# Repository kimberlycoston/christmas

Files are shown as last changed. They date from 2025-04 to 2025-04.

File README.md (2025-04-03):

# christmas
cd existing_repo
git remote add origin https://gitlab.oit.duke.edu/coston_individual2_aipi590/coston_individual2_aipi590.git
git branch -M main
git push -uf origin main
# Christmas in a Box

A festive, plug-and-play projection mapping system that lights up your home—without the hassle, cost, or danger of traditional holiday lights.

## 📌 Table of Contents
Introduction  
Features  
Hardware & Software Requirements  
Installation & Setup  
How It Works  
Challenges  
Next Steps  
Acknowledgments  
License  

## 📝 Introduction
This project is a holiday light projection mapping system built using a Raspberry Pi, camera, and mini projector housed inside a themed “gingerbread house” container. It captures the shape of a house and overlays light animations—bringing joy utilizing computer vision.

### 💡 Why This Matters?

Hanging outdoor holiday lights is time-consuming and risky

Hiring professionals is expensive

This system offers a safer, fun, and automated alternative using computer vision and projection mapping

This project runs locally on a Raspberry Pi for low-cost, real-time processing.

### 🔹 Features
✔️ Automatically detects house shape using Pi Camera
✔️ Projects holiday lights and animations without physical setup
✔️ Portable "Christmas in a Box" housing
✔️ Interactive servo-powered features (e.g., sliding door, LCD display, holiday audio jingle)
✔️ Runs entirely on a Raspberry Pi  

## 💻 Hardware & Software Requirements
### 🔧 Hardware:
Raspberry Pi 4  
Mini Projector  
Pi Camera  
Continuous Servo Motor (for gingerbread house door)  
Button (to capture photo)  
Button (to open/close door)  
LED Display  
Real-time Clock Module  
Containment device (custom-built gingerbread house enclosure)  
USB Cable, HDMI Cable, Power Supply (5V Battery Pack), Wires, Breadboard  



### 📦 Software:
Python 3.7+    
NumPy  
OpenCV  
VLC (for video projection demo)  
Roboflow  
Window Object Detection Dataset for computer vision model (Project ID: door-window-detection-pipvh-xcnsz)  
Roof & Trim Instance Segmentation Dataset for computer vision model (Project ID: dzinlyinstancesegmentation-welbr)  

## ⚙️ Installation & Setup
### Step 1: Clone the Repository
git clone https://gitlab.oit.duke.edu/coston_individual2_aipi590/coston_individual2_aipi590.git 
cd christmas 

### Step 2: Install Dependencies
pip install -r requirements.txt  

### Step 3: Hardware Assembly
Connect Pi Camera to Raspberry Pi via ribbon  
Connect Mini Projector to Raspberry Pi via HDMI cable  
Connect buttons, RTC module, passive buzzer, and LCD display using GPIO pins  
Create track for door to run on servo motor (.stl files for 3D printed rack & pinion; can choose between two sizes of pinions)  
Secure all components inside your chosen [e.g., gingerbread house] enclosure (.svg files for laser cut gingerbread house)  

### Step 4: Run the Program
Press the button to demo the system (will open/close door via servo)  
Press the second button and camera captures and maps the projection area  
Light animation video plays through the projector     

## 📊 How It Works
User sets up the “Christmas in a Box” facing their house  
Press button → servo opens door → projector lens revealed  
Pi Camera captures house image  
OpenCV detects edges or key shapes (windows, roofline)  
Light animation is aligned to contours and projected  
Servo and buzzer add interactive, festive effects :)  

### 📌 Flowchart of the System:
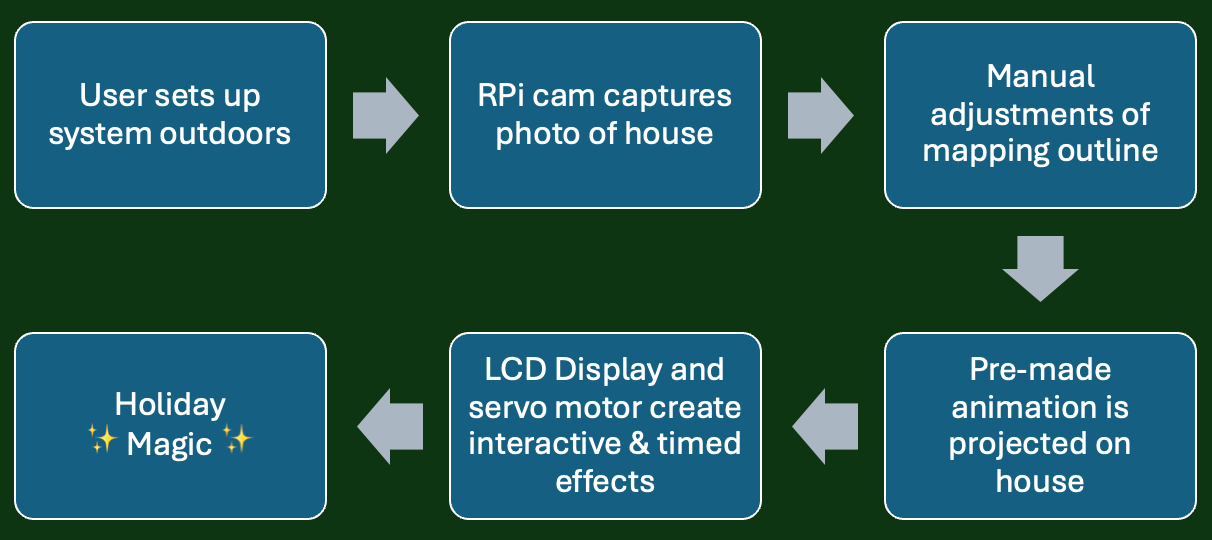
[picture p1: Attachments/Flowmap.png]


## 🚧 Challenges
🔴 IR Blaster Integration  
Initially planned for IR-controlled lights but ran into signal issues; feature was skipped in final build.

🔴 Containment Device Design  
Multiple iterations on how to house all components—limited space and aesthetics were hard to balance.

🔴 Servo Timing & Constraints  
Servo motor movement had to be extremely precise within the tight enclosure space.

🔴 Projection Alignment Issues  
Accurate projection mapping onto the house was challenging—OpenCV had trouble with lighting variation and inconsistent surfaces.

## 🚀 Next Steps
✔️ Improve projection alignment accuracy  
✔️ Add customizable light themes and interactive modes  
✔️ Find a work-around IR or wireless syncing with external light devices  
✔️ Upgrade detection system for better edge and feature detection  
✔️ Add mobile or voice control for convenience  

## 📜 License
This project is licensed under the MIT License – feel free to use and modify it.

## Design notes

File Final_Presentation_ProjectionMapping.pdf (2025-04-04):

# Holiday Light

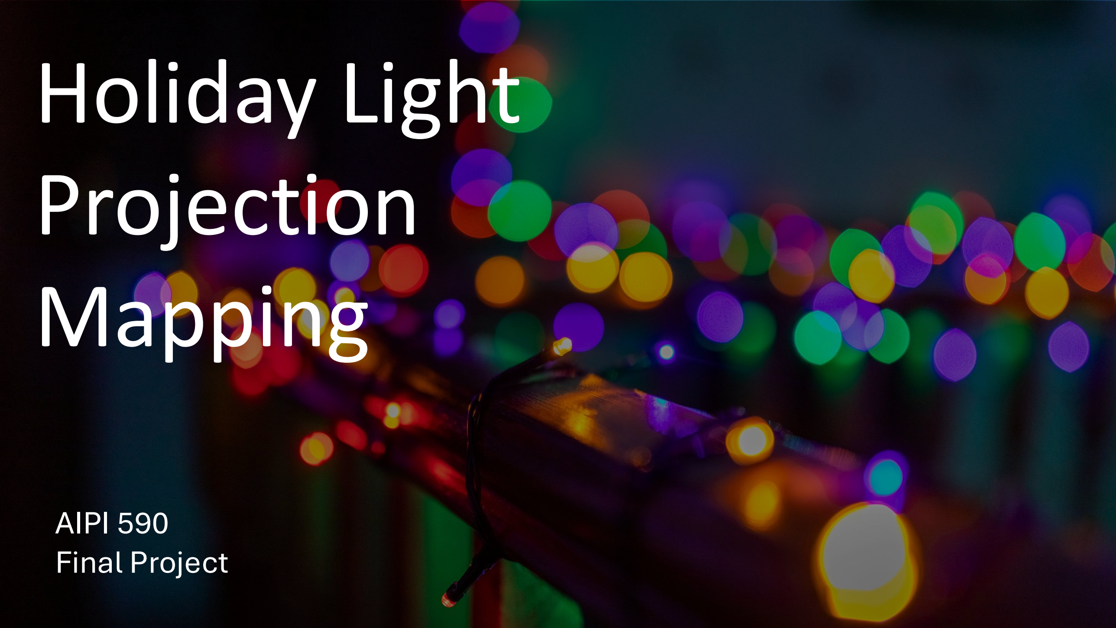
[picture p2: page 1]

# Projection Mapping

AIPI 590
Final Project

# Background: Time, Cost, & Safety

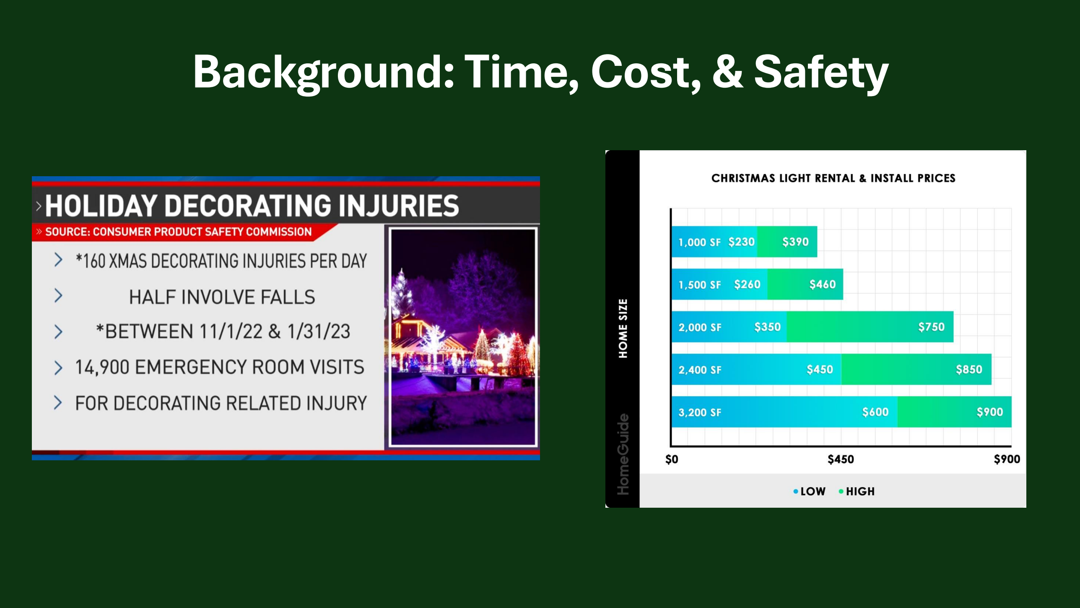
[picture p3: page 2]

# Sensors, Inputs, & Peripherals

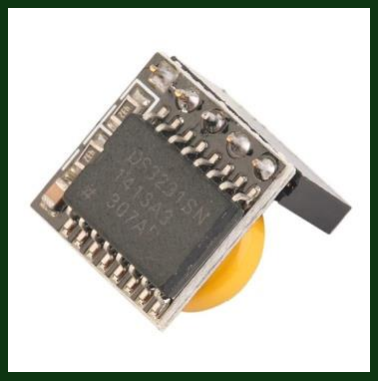
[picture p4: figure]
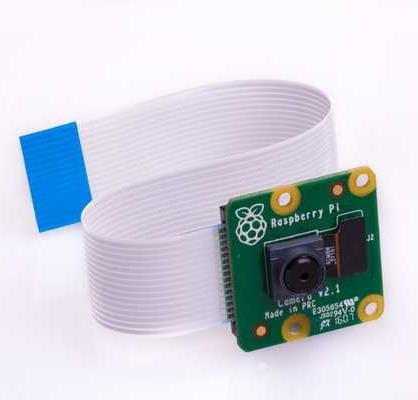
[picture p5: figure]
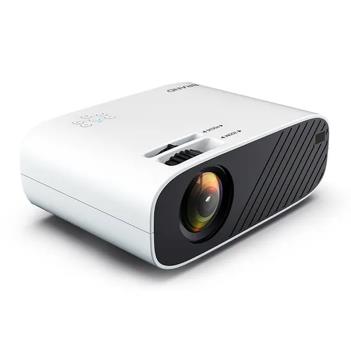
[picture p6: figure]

- RPi Camera Module 2
- Push Button x2

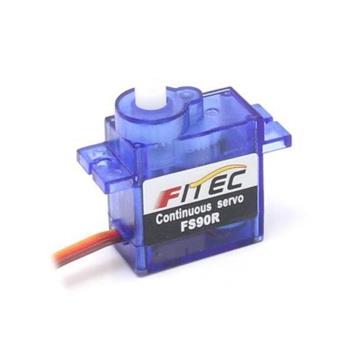
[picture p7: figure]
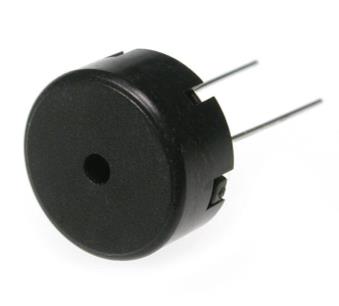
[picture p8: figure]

- DS3231 Real Time Clock Module
- LCD 16x2 Display
- Passive Buzzer
- FS90R Continuous Servo Motor
- Mini Projector

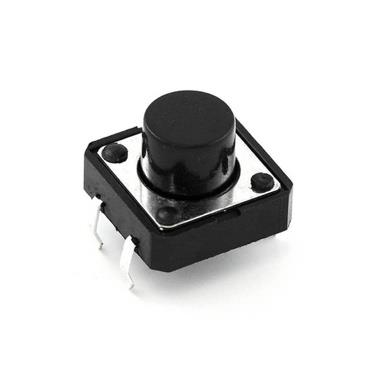
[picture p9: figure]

# Dataset + Model Prediction

Model
- Instance segmentation
- Ultralytics YOLOv8n
- Roboflow
- 298 images
- Epochs: 50
Class | Precision | Recall | mAP@0.5 | mAP@0.5:0.95
Roof | 0.678 | 0.812 | 0.828 | 0.704
Trim | 0.772 | 0.640 | 0.774 | 0.550
Window | 0.884 | 0.822 | 0.930 | 0.772

Postprocessing
- Extract external contours via OpenCV
- Apply class-specific filtering:
- Window: convert to bounding rectangle
- Trim: Keep as polyline, no mask fill
- Roof: smooth shape, remove jittery edges Model Performance

# Postprocessing Example

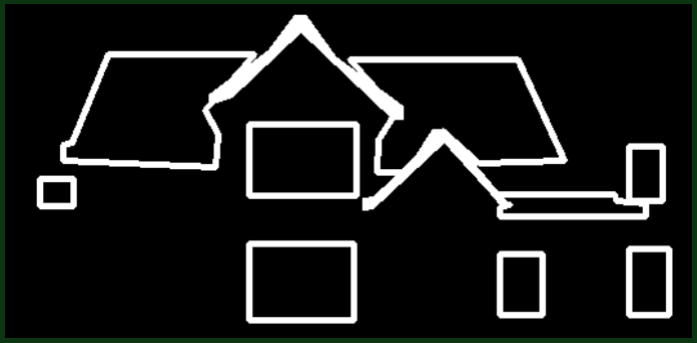
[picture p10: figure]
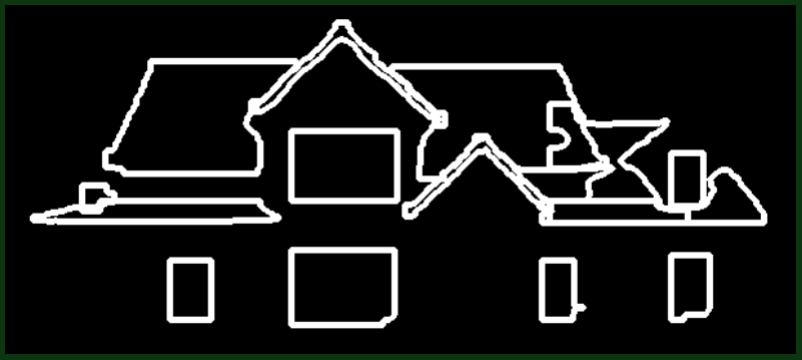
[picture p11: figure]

# Process

## Control Module

- Servo control
- LCD screen feedback
- Sound effects
- RTC time tracking
- Demo button

## Vision Module

- capture_utils
- yolo_utils
- ui_utils
- edit_utils

## Projection Module

- Overlay GIFs
- Sends to projector

# Challenges

## - IR blaster integration - Designing the container - Servo motor precision - Projection mapping accuracy

# How it Works

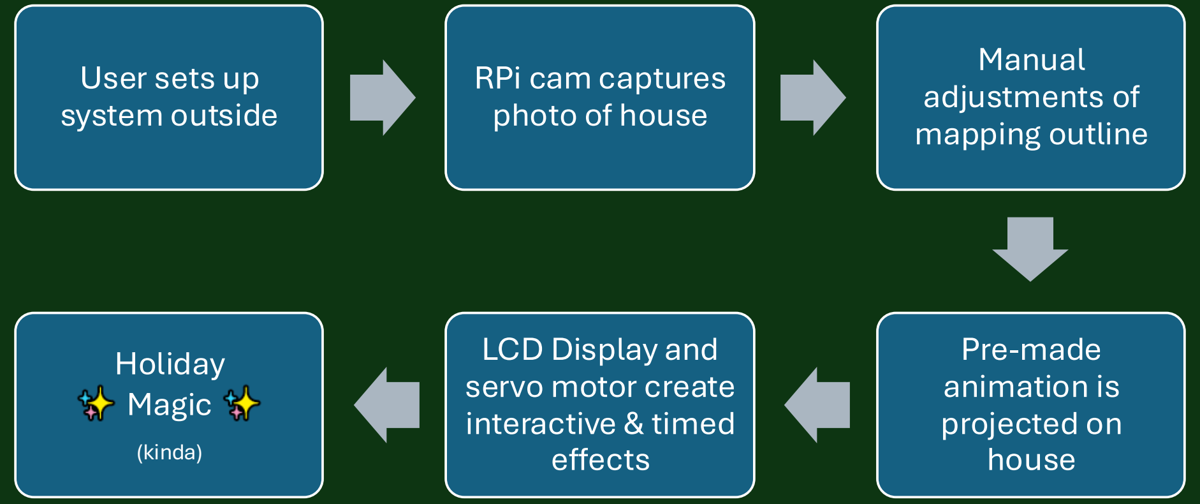
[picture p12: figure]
User sets up system outside; RPi cam captures photo of house; Manual adjustments of mapping outline; Pre-made animation is projected on house; LCD Display and servo motor create interactive & timed effects; Holiday Magic; (kinda)

# Demo

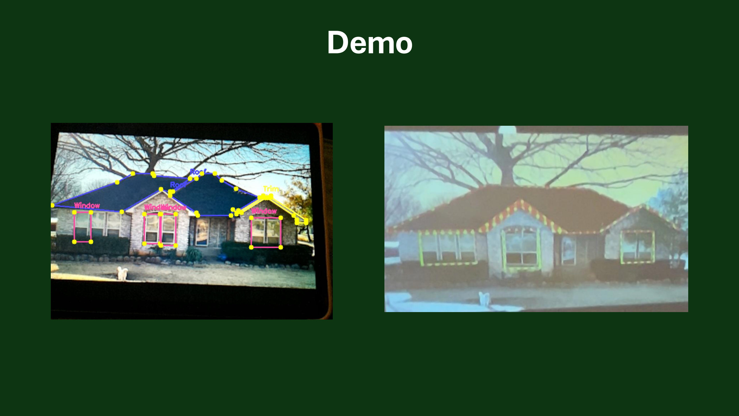
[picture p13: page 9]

# Next Steps

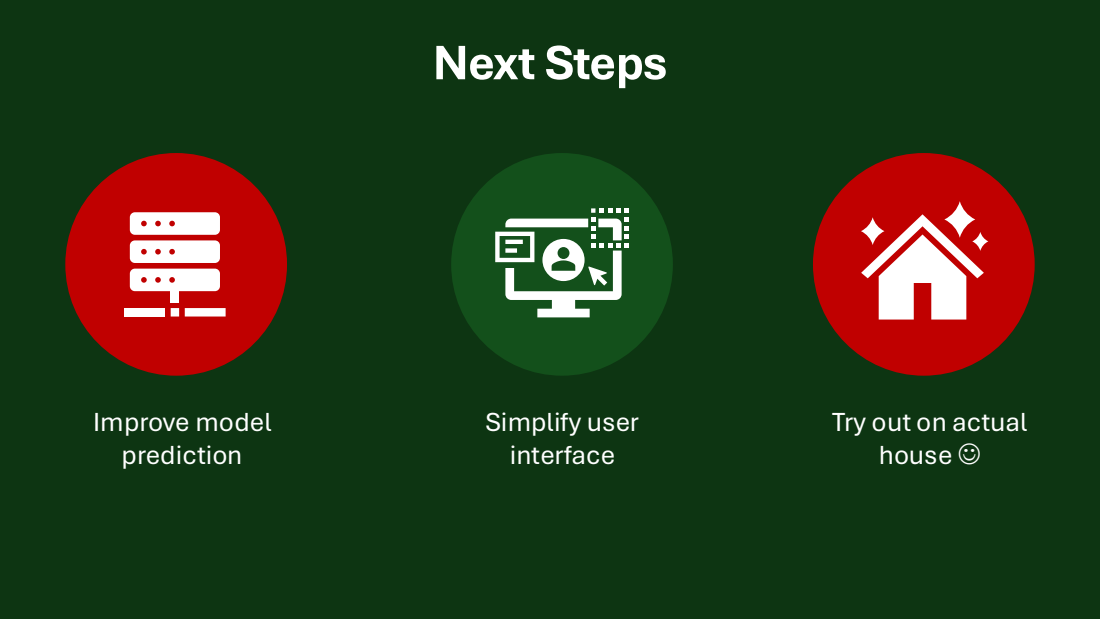
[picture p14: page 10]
Simplify user interface; Improve model prediction

Try out on actual
house ☺

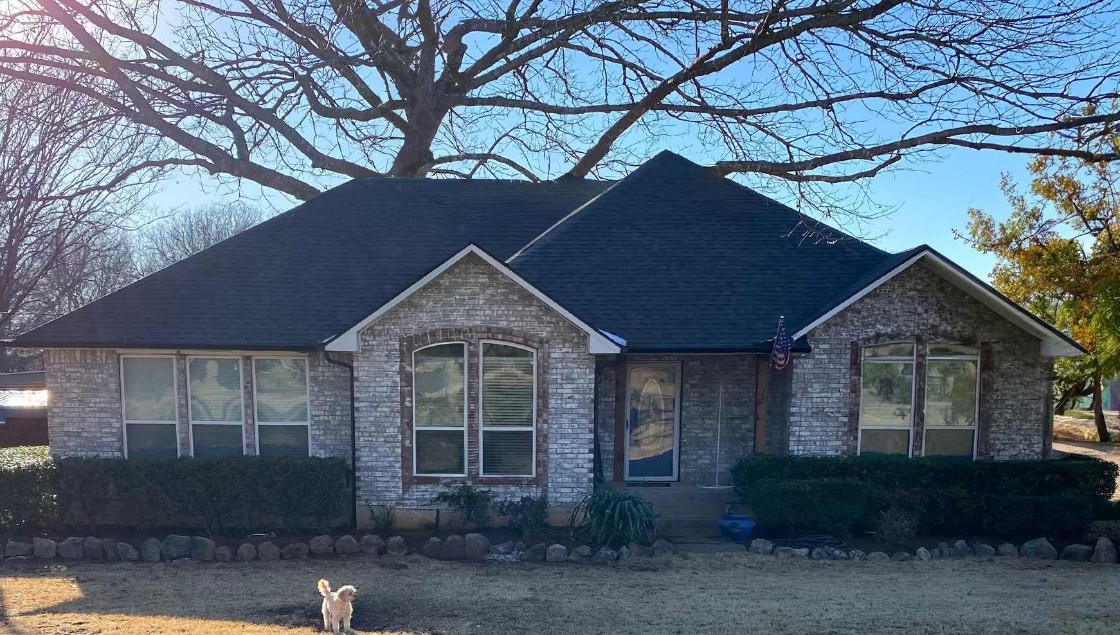
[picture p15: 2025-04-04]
mom_house_final.png

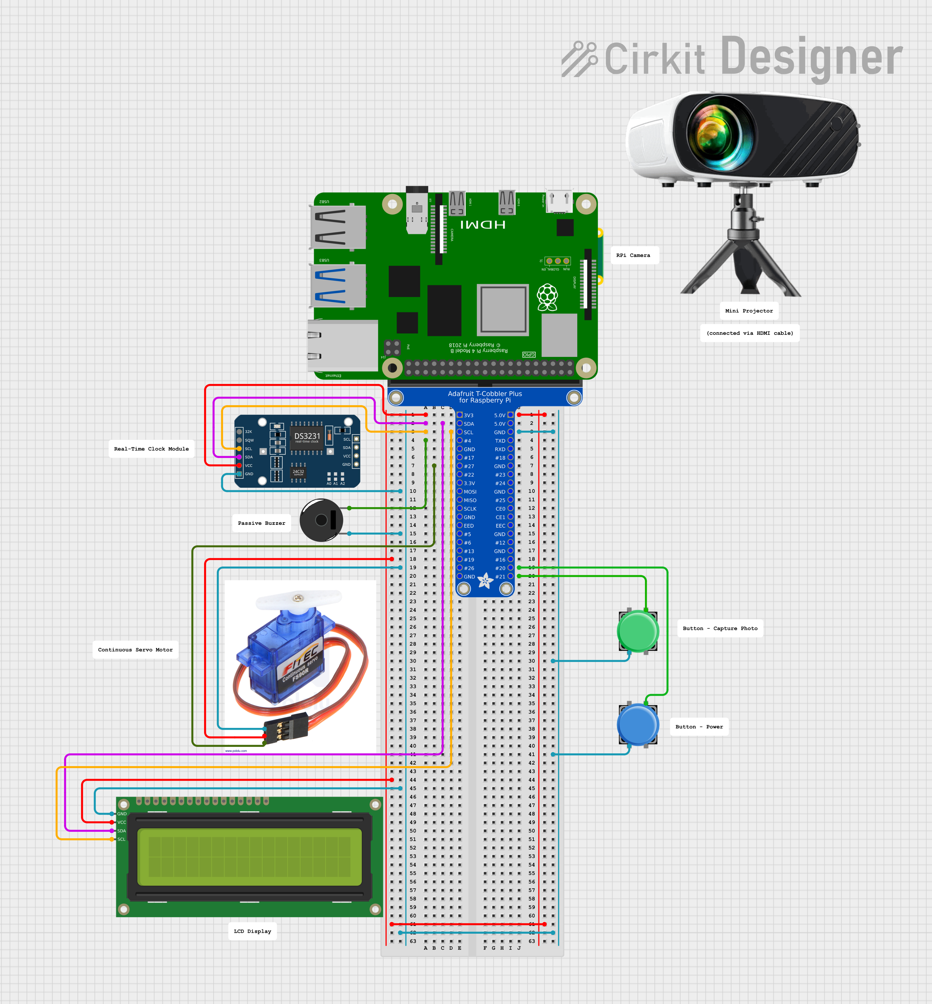
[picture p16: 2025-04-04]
Circuit_diagram.png

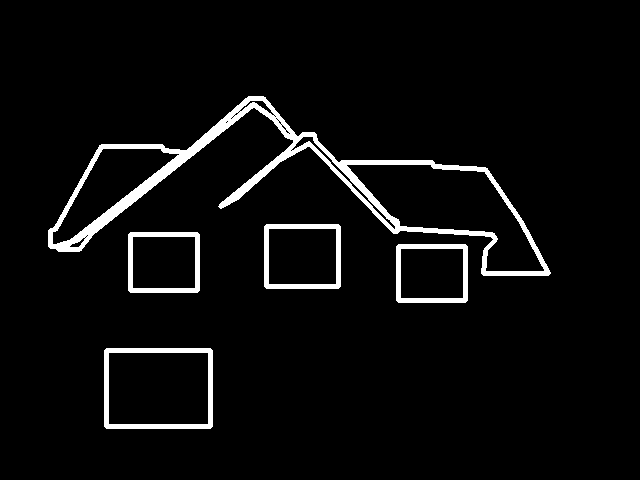
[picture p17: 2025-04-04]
mask_dynamic.png

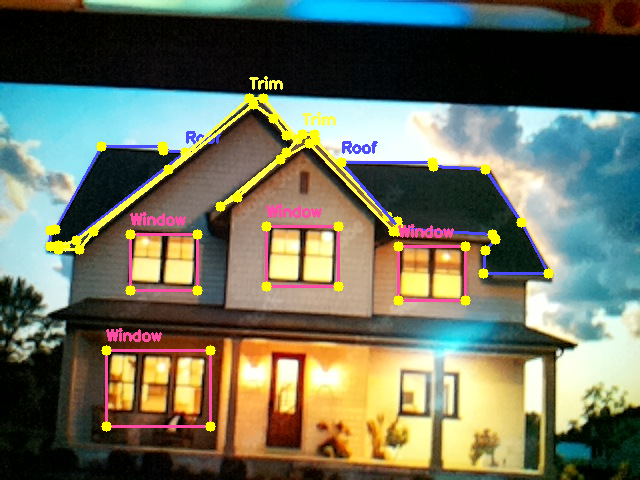
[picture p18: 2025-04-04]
overlay_dynamic_final.png

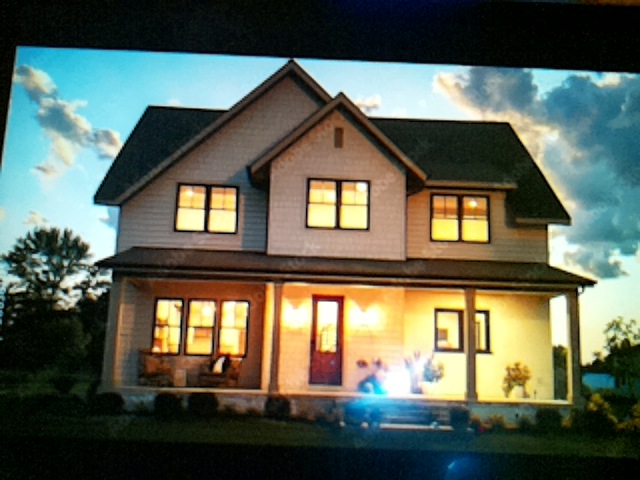
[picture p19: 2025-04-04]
captured_image_20250404_061623.jpg

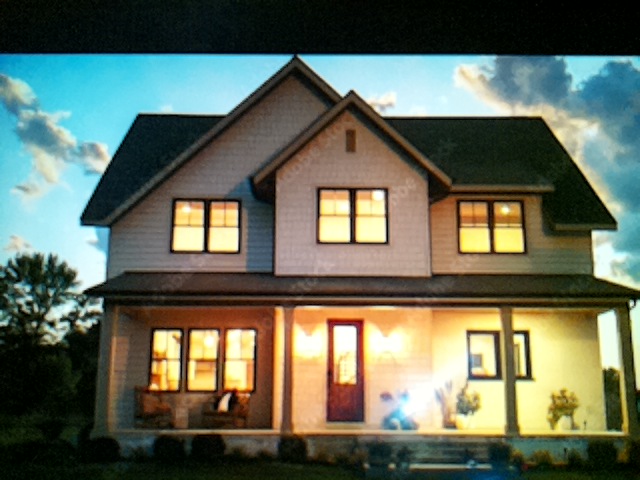
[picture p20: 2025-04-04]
captured_image_20250404_061312.jpg

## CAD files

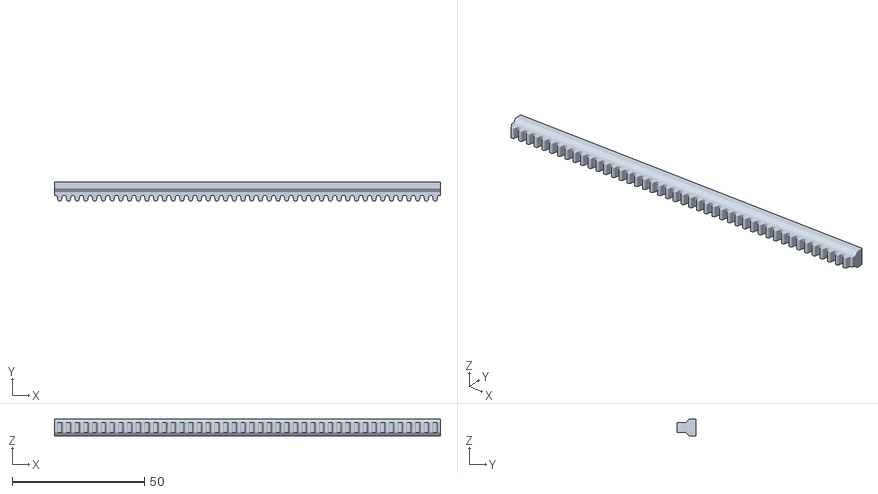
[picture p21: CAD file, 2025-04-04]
Additional Print Files/rack.stl
146.0 x 7.20 x 6.35

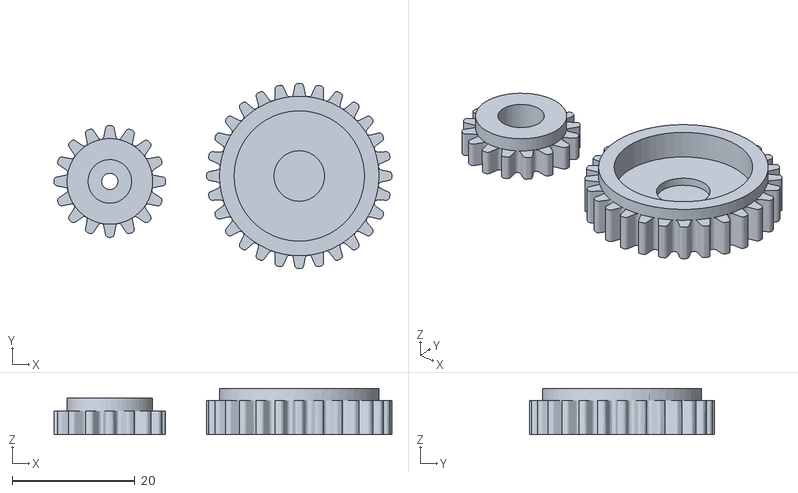
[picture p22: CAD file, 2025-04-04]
Additional Print Files/pinions.stl
55.1 x 30.2 x 7.51

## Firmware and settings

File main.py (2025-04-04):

# main.py
from gpiozero import Button
from gpiozero.pins.pigpio import PiGPIOFactory
import threading
from control_module.control import open_door, close_door, get_current_time, show_boot_message, time_until_event, lcd_message, setup_test_button, shutdown
# from vision_module.vision import capture_image
from vision_module.yolo_utils import run_yolo
from vision_module.capture_utils import capture_image
from vision_module.ui_utils import launch_editor
from vision_module.edit_utils import edit_mask_interactively
from projection import play_animated_projection




import time

# State flags for door
opened = False
closed = False

# Set up PiGPIO
factory = PiGPIOFactory()

# Set up photo button
photo_button = Button(21, pull_up=True, pin_factory=factory, bounce_time=0.2)
# Set up test button
test_button = Button(22, pull_up=True, pin_factory=factory, bounce_time=0.2)


def handle_photo_press():
    print("Button pressed to capture image")
    lcd_message("Taking picture", "Please wait...")
    image = capture_image()
    lcd_message("Done!", "Image captured")

    launch_editor(image, initial_conf=0.6)  # User edits as needed

    # After editing, immediately continue to lights
    lcd_message("Displaying lights", "Enjoy the show!")
    print("Starting animated projection")
    play_animated_projection("mask_dynamic.png", "gifs/colors.gif")


photo_button.when_pressed = handle_photo_press

def rtc_loop():
    global opened, closed
    while True:
        now = get_current_time()
        hour = now.tm_hour
        minute = now.tm_min

        if hour == 18 and minute == 0 and not opened:
            open_door()
            opened = True
            closed = False
        elif hour == 6 and minute == 0 and not closed:
            close_door()
            closed = True
            opened = False

        # Display countdown on LCD
        if 6 <= hour < 18:
            hrs, mins = time_until_event(now, 18)
            lcd_message("Open in:", f"{hrs:02}h {mins:02}m remains")
        else:
            hrs, mins = time_until_event(now, 6)
            lcd_message("Magic sleeps in:", f"{hrs:02}h {mins:02}m")

        time.sleep(20)

try:
    show_boot_message()
    setup_test_button()  # ✅ This sets up the demo test button on GPIO 22
    threading.Thread(target=rtc_loop, daemon=True).start()

    # Keep main thread alive
    while True:
        time.sleep(1)

except KeyboardInterrupt:
    print("Shutting down...")
    lcd_message("Shutting down...")
    time.sleep(1)
    shutdown()  # ✅ calls cleanup from control.py

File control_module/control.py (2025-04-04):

from gpiozero import Servo, Button
from gpiozero.pins.pigpio import PiGPIOFactory
from time import sleep
import board
import busio
import adafruit_ds3231
import threading
from RPLCD.i2c import CharLCD
from datetime import datetime, timedelta
from control_module.buzzer_utils import play_melody


# === SETUP ===

# PiGPIO for servo + button (ensure pigpiod is running!)
factory = PiGPIOFactory()

# Servo using your tested pulse widths
servo = Servo(17, pin_factory=factory, min_pulse_width=0.0005, max_pulse_width=0.0025)
servo.value = 0
sleep(0.3)
servo.detach()

# LCD (adjust I2C address if needed)
lcd = CharLCD('PCF8574', 0x27)

# RTC (DS3231)
i2c = busio.I2C(board.SCL, board.SDA)
rtc = adafruit_ds3231.DS3231(i2c)

# Test mode for live class demo
import threading
test_toggle = [True]
test_lock = threading.Lock()

# === LIVE CLASS DEMO ===
def handle_test_press():
    if test_lock.locked():
        return  

    with test_lock:
        if test_toggle[0]:
            lcd_message("Test: Opening")
            print("Test mode: Opening")
            open_door()
        else:
            lcd_message("Test: Closing")
            print("Test mode: Closing")
            close_door()
        test_toggle[0] = not test_toggle[0]
        sleep(0.5)  # small delay to avoid bouncing

def setup_test_button():
    global test_button
    test_button = Button(20, pull_up=True, pin_factory=factory, bounce_time=0.2)
    test_button.when_pressed = handle_test_press

# === FUNCTIONS ===

def lcd_message(line1="", line2=""):
    lcd.clear()
    lcd.cursor_pos = (0, 0)
    lcd.write_string(line1[:16])
    lcd.cursor_pos = (1, 0)
    lcd.write_string(line2[:16])

def open_door():
    print("Opening door...")
    lcd_message("Opening door...")
    servo.value = 0.08
    sleep(2.1)
    servo.value = 0
    sleep(0.3)
    servo.detach()
    play_melody()

def close_door():
    print("Closing door...")
    lcd_message("Closing door...")
    servo.value = -0.11
    sleep(2.6)
    servo.value = 0
    sleep(0.3)
    servo.detach()

def get_current_time():
    return rtc.datetime

def time_until_event(now, target_hour):
    """Returns (hours, minutes) until target hour (24h format)"""
    current_time = datetime(now.tm_year, now.tm_mon, now.tm_mday, now.tm_hour, now.tm_min)
    target_time = datetime(now.tm_year, now.tm_mon, now.tm_mday, target_hour, 0)

    if target_time <= current_time:
        # If target time already passed today, set it for tomorrow
        target_time += timedelta(days=1)

    delta = target_time - current_time
    hours, remainder = divmod(delta.seconds, 3600)
    minutes = remainder // 60
    return hours, minutes

def show_boot_message():
    lcd_message("Booting up...")
    sleep(2)
    lcd.clear()

def shutdown():
    print("Detaching servo and cleaning up...")
    servo.detach()
    lcd.clear()

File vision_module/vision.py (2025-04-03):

import cv2
import numpy as np
import colorsys
from ultralytics import YOLO
from gpiozero import Servo, Button
from gpiozero.pins.pigpio import PiGPIOFactory
from time import sleep


factory = PiGPIOFactory()


# ===============================
# GLOBAL SETUP
# ===============================
model = YOLO("best.pt")
# image_path = "mom_house_final.png"
# original_img = cv2.imread(image_path)
# original_img = capture_image()
# original_height, original_width = original_img.shape[:2]
# resized_img = cv2.resize(original_img, (640, 640))

window_name = "Preview"
current_conf = 0.6
visible_classes = set()
selected_contour_idx = -1
selected_point_idx = -1
is_dragging = False
last_slider_conf = -1  # to detect slider changes
undo_stack = []

# Take a live picture from the Pi camera
def capture_image():
    cap = cv2.VideoCapture(0)  # 0 = default Pi camera
    sleep(2)  # Give time for camera to warm up
    ret, frame = cap.read()
    cap.release()
    if ret:
        cv2.imwrite("captured_image.jpg", frame)
        print("📷 Photo button pressed — running YOLO again")
        return frame
    else:
        raise Exception("Failed to capture image")
    
original_img = capture_image()
original_height, original_width = original_img.shape[:2]
resized_img = cv2.resize(original_img, (640, 640))

# Button setup to take a photo
photo_button = Button(23, pull_up=True, pin_factory=factory, bounce_time=0.2)

def handle_photo_press():
    print("📸 Taking photo!")
    global original_img, resized_img, original_height, original_width
    original_img = capture_image()
    original_height, original_width = original_img.shape[:2]
    resized_img = cv2.resize(original_img, (640, 640))
    update_contours(current_conf)

photo_button.when_pressed = handle_photo_press


# Helper: Generate consistent colors

def generate_class_colors(class_names):
    hsv = [(i / len(class_names), 0.7, 1.0) for i in range(len(class_names))]
    rgb = [tuple(int(c * 255) for c in colorsys.hsv_to_rgb(*h)) for h in hsv]
    return {cls: color for cls, color in zip(class_names, rgb)}

# Dummy callback for trackbar
def nothing(x):
    pass

# ===============================
# INTERACTION STORAGE
# ===============================
all_contours = []  # List of (cnt, class_name)
mouse_x, mouse_y = -1, -1

# ===============================
# MOUSE EVENTS
# ===============================
def mouse_callback(event, x, y, flags, param):
    global selected_contour_idx, selected_point_idx, is_dragging, mouse_x, mouse_y
    mouse_x, mouse_y = x * 2, y * 2

    if event == cv2.EVENT_LBUTTONDOWN:
        for idx, (cnt, _) in enumerate(all_contours):
            for pt_idx, pt in enumerate(cnt):
                px, py = pt[0]
                if abs(px - mouse_x) < 10 and abs(py - mouse_y) < 10:
                    selected_contour_idx = idx
                    selected_point_idx = pt_idx
                    is_dragging = True
                    return

        for idx, (cnt, class_name) in enumerate(all_contours):
            if cv2.pointPolygonTest(cnt, (mouse_x, mouse_y), False) >= 0:
                undo_stack.append(list(all_contours))
                print(f"🗑️ Deleted: {class_name}")
                all_contours.pop(idx)
                return

    elif event == cv2.EVENT_LBUTTONUP:
        is_dragging = False

    elif event == cv2.EVENT_MOUSEMOVE and is_dragging:
        if 0 <= selected_contour_idx < len(all_contours):
            cnt, class_name = all_contours[selected_contour_idx]
            cnt[selected_point_idx][0] = [mouse_x, mouse_y]

# ===============================
# INITIALIZATION
# ===============================
cv2.namedWindow(window_name)
cv2.setMouseCallback(window_name, mouse_callback)
cv2.createTrackbar("Confidence", window_name, int(current_conf * 100), 100, nothing)

# Initial prediction to get class names
initial_results = model.predict(source=resized_img, conf=current_conf, verbose=False, task='segment')
class_names = list(initial_results[0].names.values())
class_colors = generate_class_colors(class_names)
visible_classes = set(class_names)

# Store contours once

def update_contours(conf):
    global all_contours, selected_contour_idx, selected_point_idx, is_dragging
    selected_contour_idx = -1
    selected_point_idx = -1
    is_dragging = False
    global all_contours
    all_contours = []
    results = model.predict(source=resized_img, conf=conf, verbose=False, task='segment')
    if results[0].masks is not None:
        for i, mask in enumerate(results[0].masks.data):
            class_id = int(results[0].boxes.data[i][5])
            class_name = results[0].names[class_id]
            if class_name not in visible_classes:
                continue
            resized_mask = cv2.resize(mask.cpu().numpy().astype(np.uint8) * 255, (original_width, original_height))
            contours, _ = cv2.findContours(resized_mask, cv2.RETR_EXTERNAL, cv2.CHAIN_APPROX_SIMPLE)
            for cnt in contours:
                if cv2.contourArea(cnt) > 100:
                    epsilon = 0.01 * cv2.arcLength(cnt, True)
                    smoothed_cnt = cv2.approxPolyDP(cnt, epsilon, True)
                    all_contours.append((smoothed_cnt, class_name))

# Initial load
update_contours(current_conf)
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

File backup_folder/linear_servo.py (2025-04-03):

from gpiozero import Servo
from time import sleep
from gpiozero.pins.pigpio import PiGPIOFactory

# Use PiGPIOFactory for better PWM accuracy
factory = PiGPIOFactory()

# Replace 17 with your GPIO pin
servo = Servo(17, pin_factory=factory, min_pulse_width=0.0005, max_pulse_width=0.0025)

print("Starting servo test...")

try:
    while True:
        print("Full speed forward")
        servo.value = 0.08  # Full speed clockwise
        sleep(2.3)

        print("Stop")
        servo.value = 0  # Stop
        sleep(2)

        print("Full speed reverse")
        servo.value = -0.08  # Full speed counter-clockwise
        sleep(2.3)

        print("Stop")
        servo.value = 0
        sleep(2)

except KeyboardInterrupt:
    print("Stopped by user.")

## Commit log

2025-04-04 merging github gitlab git all the stuff
    [pinions.stl, rack.stl]
2025-04-04 final updates the prob screwed it up honestly
